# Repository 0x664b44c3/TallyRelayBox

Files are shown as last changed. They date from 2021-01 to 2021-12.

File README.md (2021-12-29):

# TallyRelayBox
RS-422 Tally relay box using the TSL protocol

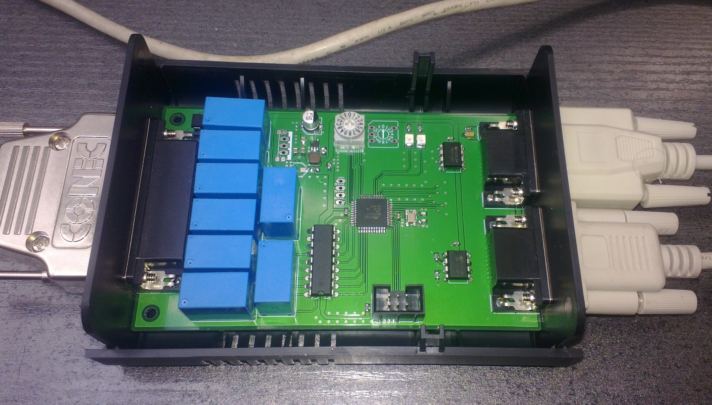
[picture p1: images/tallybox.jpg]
assembled board


## Tally?

In broadcast the "red on air lamps" on cameras, monitors etc are called "Tally". They are one of the most basic and important means of communications in a studio.
Telling both the talent(s) and the technical crew (camera operators, director, etc) which image is on air (or about to be on air next).
This hardware design is a small project that fits into this niche by extracting eight channels of tally information from an RS-422/485 link carrying TSL UMD data. 
TSL's UMD protocol is one of the de-acto standards in "the industry" when it comes to distributing UMD - under monitor display - information (see tslproducts.com) 
with several other manufacturer's rack mount monitors or multy viewers understanding it.

This UMD data can easily be generated by a PC from your video mixer software (say OBS) or by writing an adapter application to translate your hardware mixer's protocol 
to TSL if the data link is not already using this protocol anyways.

The protocol obviously could be changed to whatever you feel is appropiate. Pull requests are welcome.

## Hardware

This design is based on a ATMega324PB.

Power supply can be in the range of 8 to 24V (change relays to your operating voltage!)

## Component sourcing

Most components in this design are widely available standard parts (Mouser etc are your friends for the switchmode regulator and inductor).
If used at 12V a 7805 linear regulator can be fitted as an alternative.
The provided CAD data allows easy adaption to your
local or preferred supplier. The board can be edited in the eagle freeware version if it is shortened by a few millimeters.
Current board size is designed to fit into a cheap plastic enclosure available from Reichelt Electronik in Germany 
(https://www.reichelt.de/kleingehaeuse-135-x-95-x-45-mm-eurobox-sw-p50429.html?&nbc=1). Similar enclosures should be readily available
from several suppliers. The relays used can either be TE  OJE-SS-112LMH or other types with a compatible footprint (like SonChuan 307 series).

## Compiling and flashing

I use avr-gcc 10.2.0 with GNU make on Linux for compiling this project. Your build environment may vary.
You may have to source the device definitions for the Mega324PB from Microchip to be able to compile this project.

See setup_fuses.sh for the fuse setting of the controller.

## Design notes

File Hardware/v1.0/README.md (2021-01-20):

Layout and schematics in EAGLE 6.0 file format.
This version still has an error in the RS-422 pinout (3/8 swapped)
A corrected version will be added later on.

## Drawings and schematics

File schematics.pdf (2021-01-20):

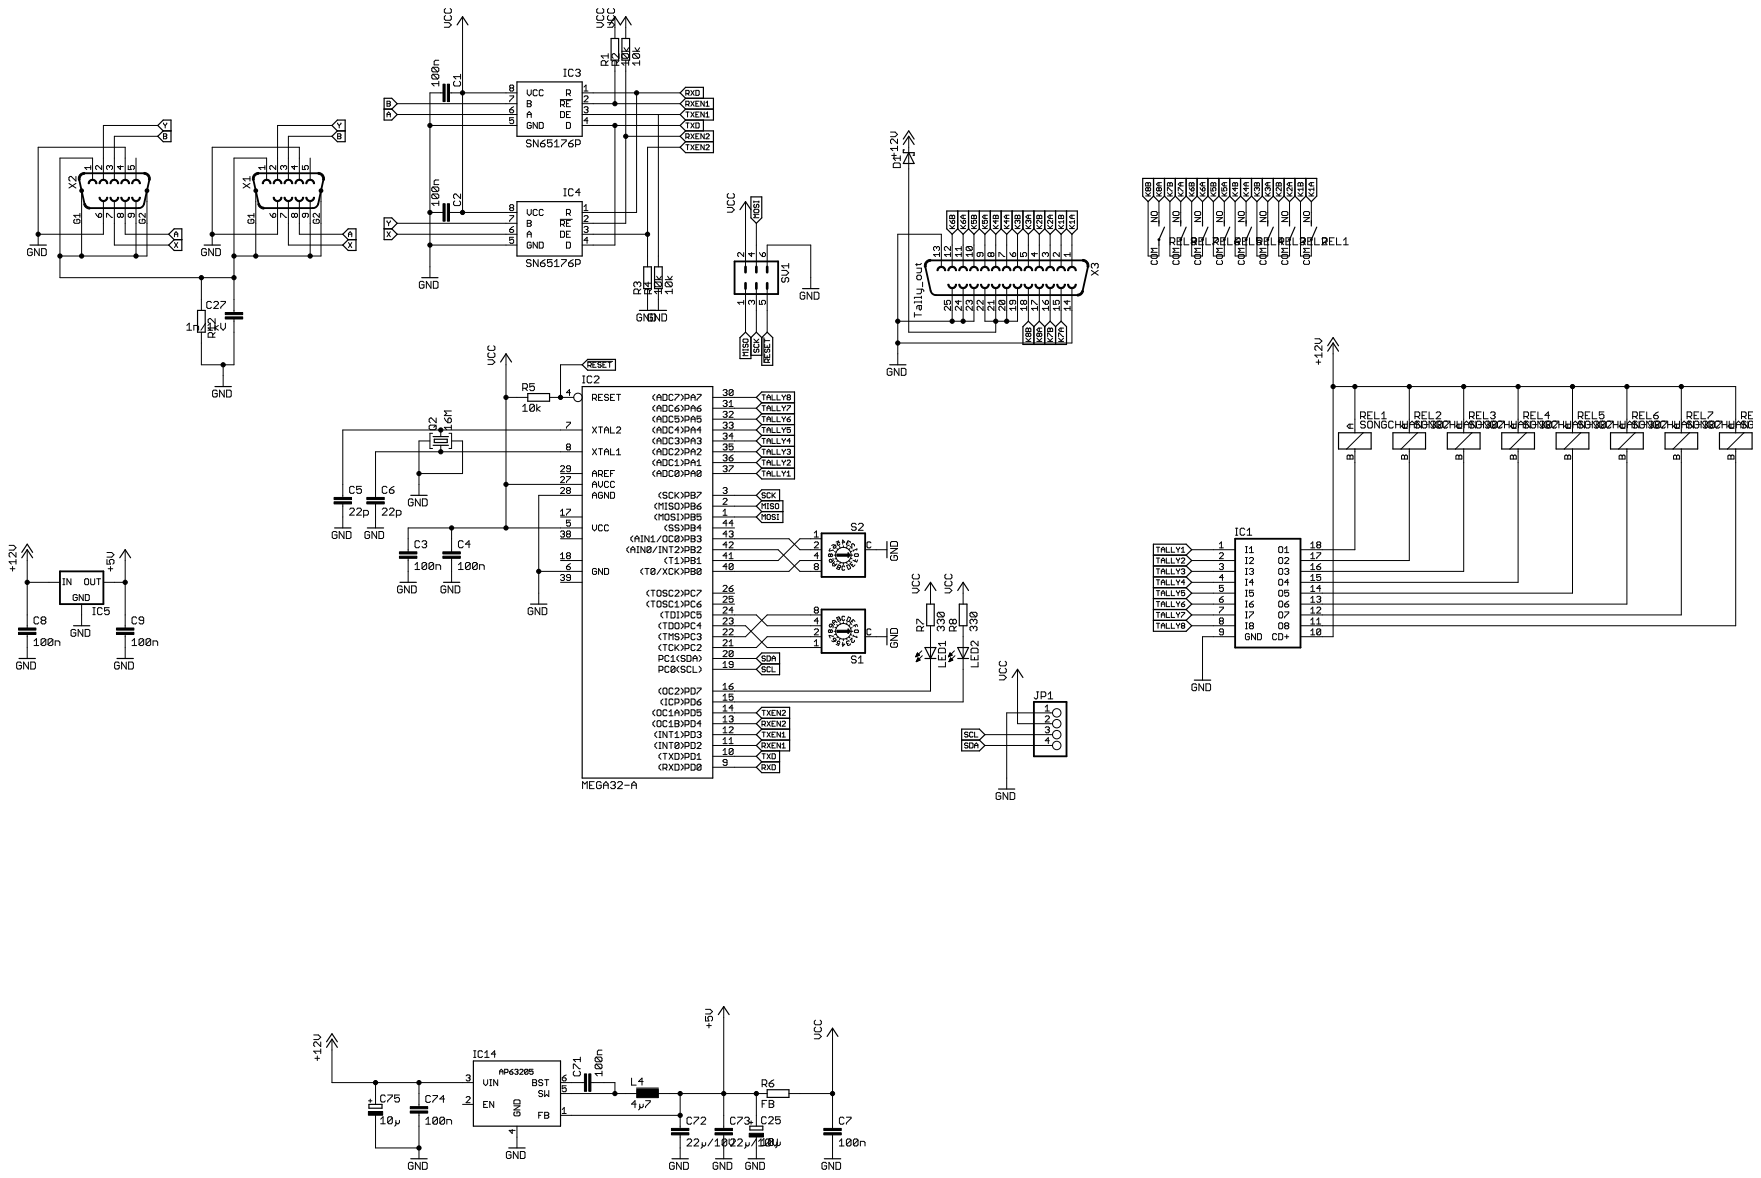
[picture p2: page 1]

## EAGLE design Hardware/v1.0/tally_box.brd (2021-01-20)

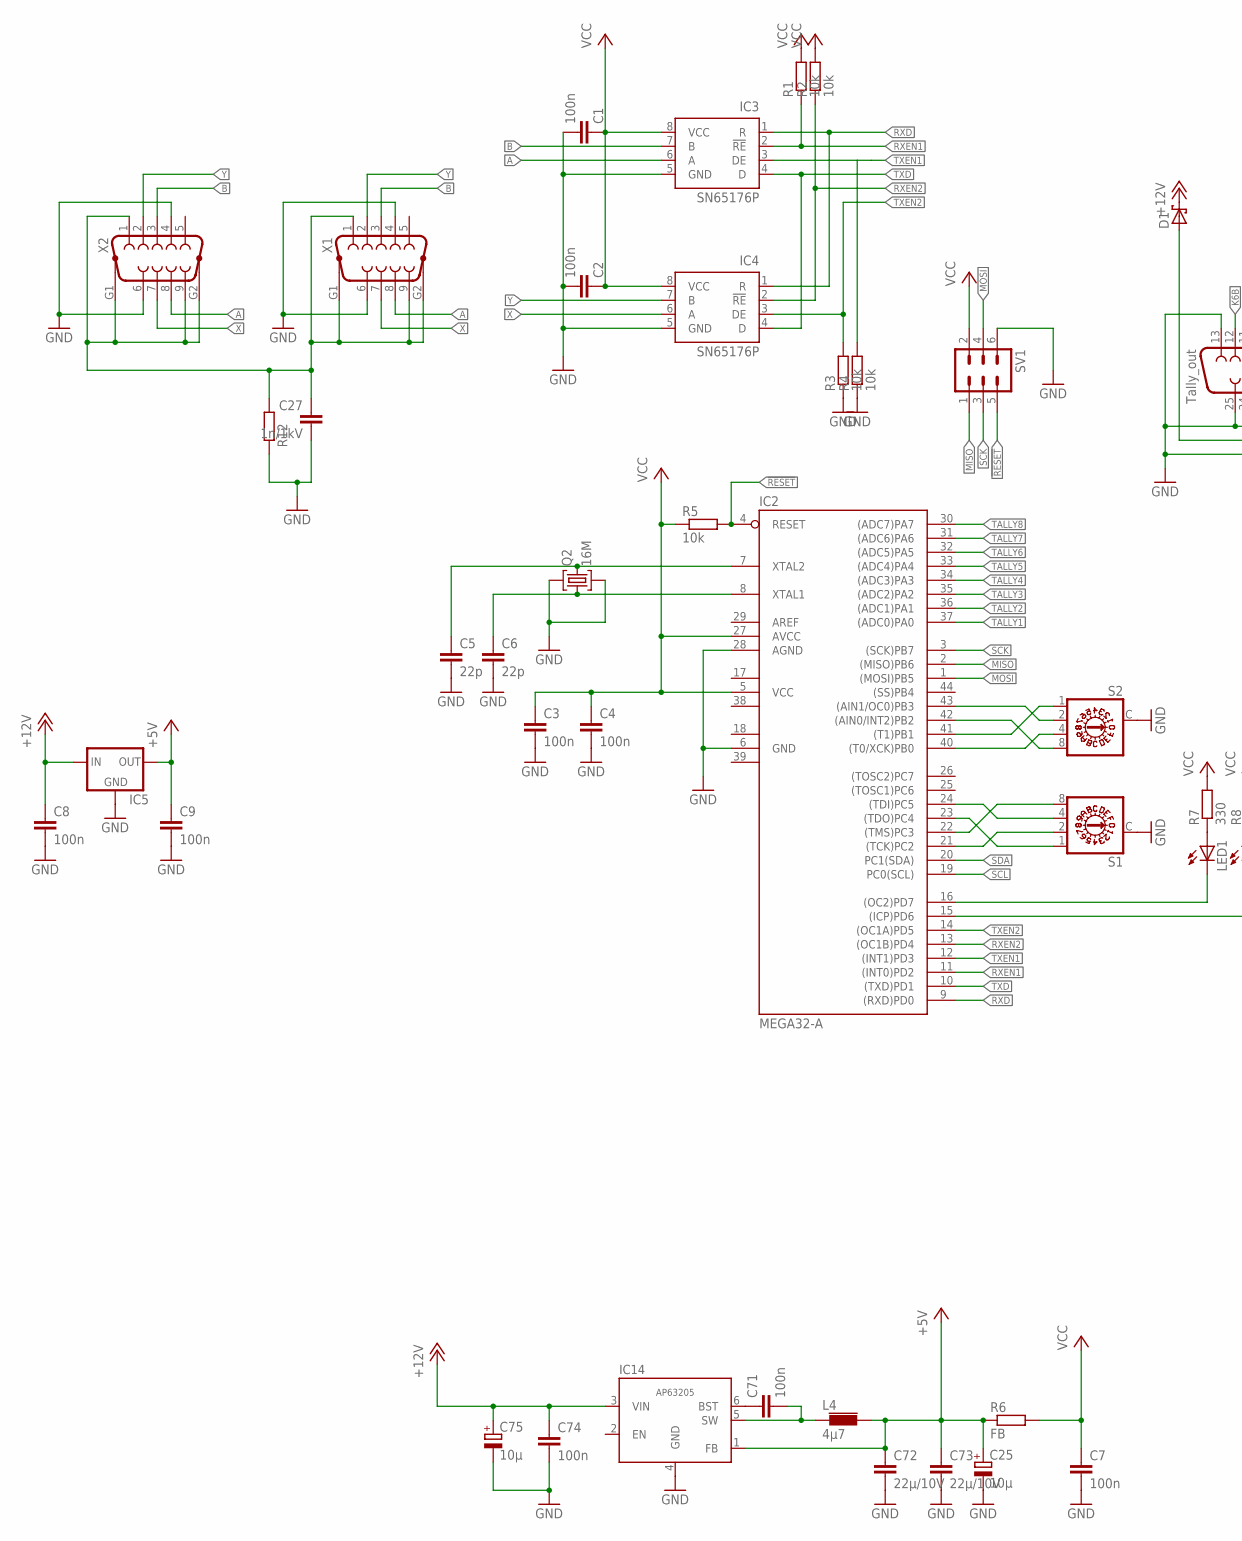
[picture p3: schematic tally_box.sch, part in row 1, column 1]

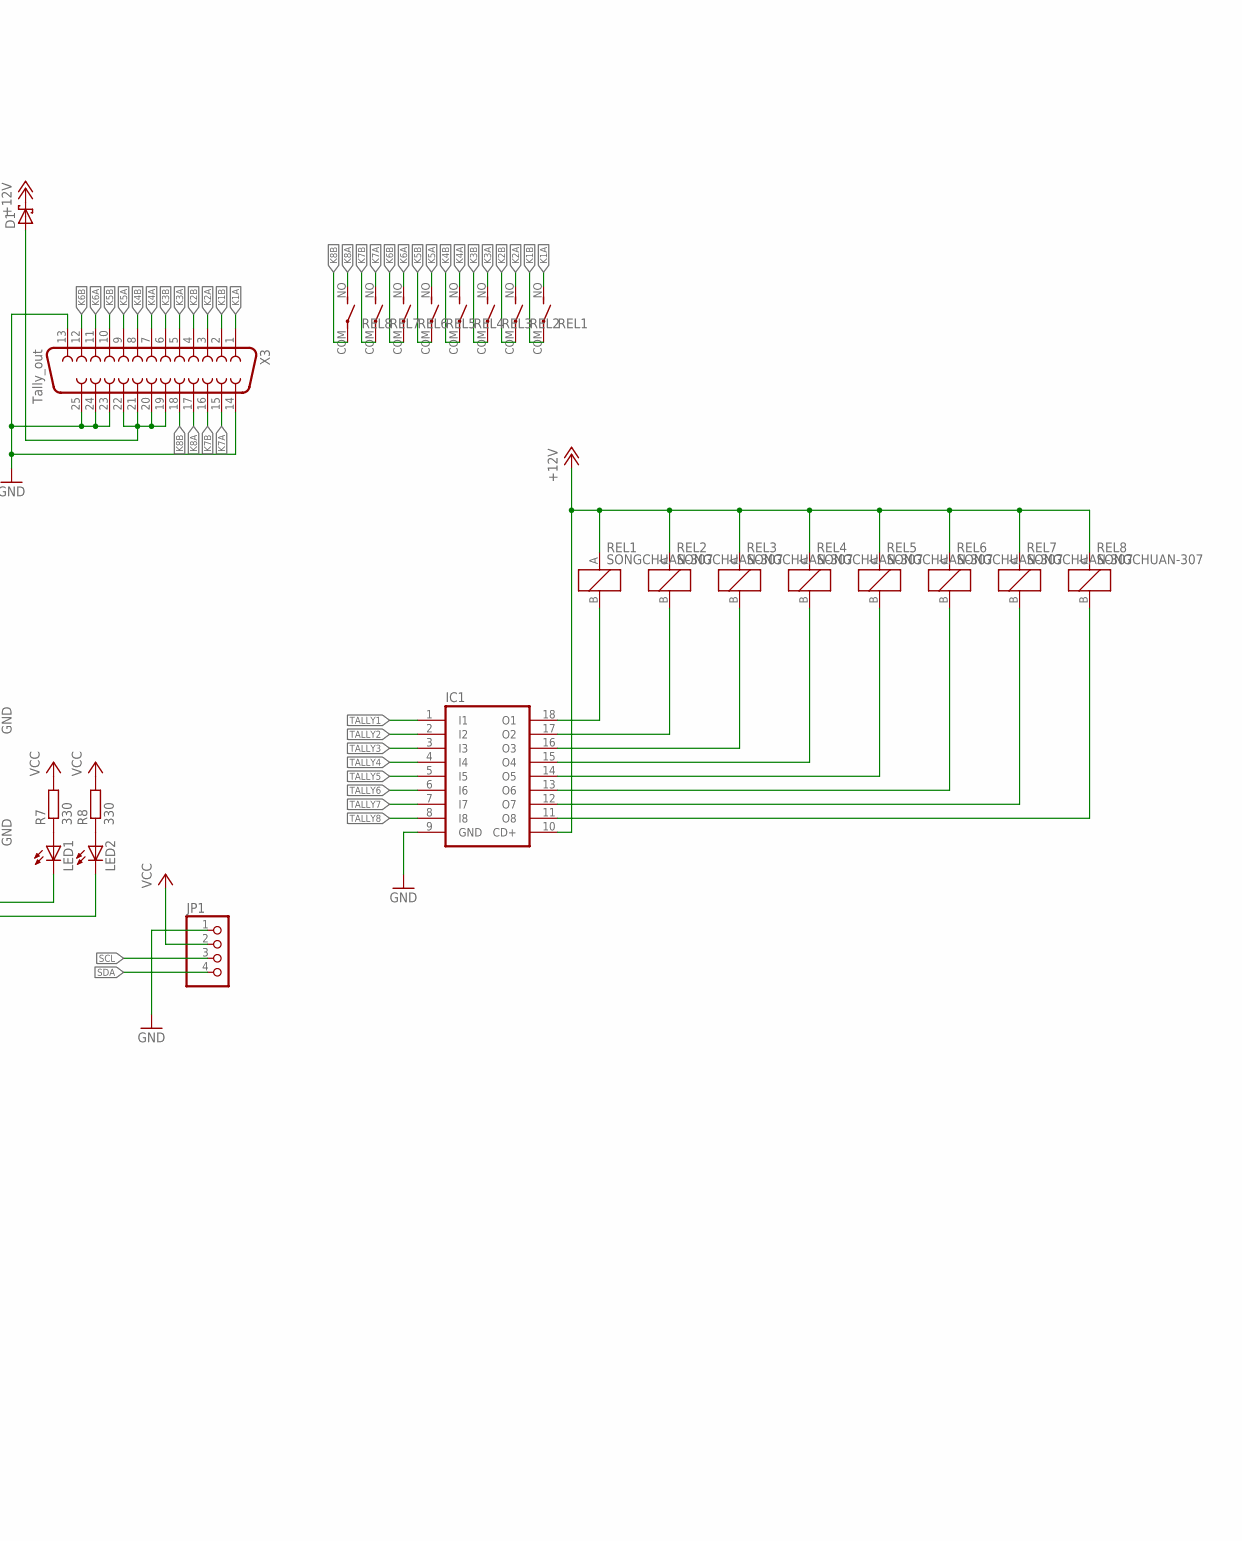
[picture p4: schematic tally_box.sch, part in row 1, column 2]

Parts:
C1, C2, C3, C4, C7: 100n; C0603
C5, C6: 22p; C0603
C8, C9, C71, C74: 100n; C0805
C25: 10µ; PANASONIC_C
C27: 1n/1kV; C1206
C72, C73: 22µ/10V; C0805
C75: 10µ; PANASONIC_D
D1: SCHOTTKY-DIODESMD; SMB
IC1: ULN2803A; DIL18
IC2: MEGA32-A; TQFP44
IC3, IC4: SN65176P; DIL08
IC5: 78XXS
IC14: AP63205; SOT23-6L
JP1: PINHD-1X4; 1X04
L4: 4µ7; TYA4020
LED1, LED2: LED-TOPLED; P-LCC-2
Q2: 16M; MJ
R1, R2, R3, R4, R5: 10k; R0603
R6: FB; R0805
R7, R8: 330; R0603
R12: R-EU_R0603; R0603
REL1, REL2, REL3, REL4, REL5, REL6, REL7, REL8: SONGCHUAN-307; SONCHUAN-307
S1, S2: A1353HEX
SV1: ML6
X1, X2: F09HP
X3: Tally_out; F25HP

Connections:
!RESET!: IC2.4 (RESET), R5.2, SV1.5
+5V: C9.1, C25.+, C72.1, C73.1, IC5.OUT, IC14.1 (FB), L4.2, R6.1
+12V: C8.1, C74.1, C75.+, D1.C, IC1.10 (CD+), IC5.IN, IC14.3 (VIN), REL1.A (+), REL2.A (+), REL3.A (+), REL4.A (+), REL5.A (+), REL6.A (+), REL7.A (+), REL8.A (+)
A: IC3.6 (A), X1.8, X2.8
AREF: IC2.29 (AREF)
B: IC3.7 (B), X1.3, X2.3
GND: C1.2, C2.2, C3.2, C4.2, C5.2, C6.2, C7.2, C8.2, C9.2, C25.-, C27.2, C72.2, C73.2, C74.2, C75.-, IC1.9 (GND), IC2.6 (GND), IC2.28 (AGND), IC3.5 (GND), IC4.5 (GND), IC5.GND, IC14.4 (GND), JP1.1, Q2.2 (G1), Q2.4 (G2), R3.1, R4.1, R12.1, S1.C, S2.C, SV1.6, X1.4, X1.6, X2.4, X2.6, X3.13, X3.14, X3.23, X3.24, X3.25
GND1: IC2.18 (GND1)
GND2: IC2.39 (GND2)
K1A: REL1.NO (S), X3.1
K1B: REL1.COM, X3.2
K2A: REL2.NO (S), X3.3
K2B: REL2.COM, X3.4
K3A: REL3.NO (S), X3.5
K3B: REL3.COM, X3.6
K4A: REL4.NO (S), X3.7
K4B: REL4.COM, X3.8
K5A: REL5.NO (S), X3.9
K5B: REL5.COM, X3.10
K6A: REL6.NO (S), X3.11
K6B: REL6.COM, X3.12
K7A: REL7.NO (S), X3.15
K7B: REL7.COM, X3.16
K8A: REL8.NO (S), X3.17
K8B: REL8.COM, X3.18
MISO: IC2.2 ((MISO)PB6), SV1.1
MOSI: IC2.1 ((MOSI)PB5), SV1.4
unnamed: IC1.18 (O1), REL1.B (-)
unnamed: IC1.17 (O2), REL2.B (-)
unnamed: IC1.16 (O3), REL3.B (-)
unnamed: IC1.15 (O4), REL4.B (-)
unnamed: IC2.23 ((TDO)PC4), S1.1
unnamed: IC2.21 ((TCK)PC2), S1.2
unnamed: IC2.22 ((TMS)PC3), S1.8
unnamed: IC2.24 ((TDI)PC5), S1.4
unnamed: IC1.14 (O5), REL5.B (-)
unnamed: IC1.13 (O6), REL6.B (-)
unnamed: IC1.12 (O7), REL7.B (-)
unnamed: IC1.11 (O8), REL8.B (-)
unnamed: IC2.43 ((AIN1/OC0)PB3), S2.2
unnamed: D1.A, X3.19, X3.20, X3.21, X3.22
unnamed: IC2.42 ((AIN0/INT2)PB2), S2.8
unnamed: IC2.41 ((T1)PB1), S2.1
unnamed: IC2.40 ((T0/XCK)PB0), S2.4
unnamed: C5.1, IC2.7 (XTAL2), Q2.3 (2)
unnamed: C6.1, IC2.8 (XTAL1), Q2.1
unnamed: IC2.16 ((OC2)PD7), LED1.C
unnamed: IC2.15 ((ICP)PD6), LED2.C
unnamed: LED1.A, R7.1
unnamed: LED2.A, R8.1
unnamed: C71.1, IC14.6 (BST)
RXD: IC2.9 ((RXD)PD0), IC3.1 (R), IC4.1 (R)
RXEN1: IC2.11 ((INT0)PD2), IC3.2 (!RE), R1.1
RXEN2: IC2.13 ((OC1B)PD4), IC4.2 (!RE), R2.1
SCK: IC2.3 ((SCK)PB7), SV1.3
SCL: IC2.19 (PC0(SCL)), JP1.3
SDA: IC2.20 (PC1(SDA)), JP1.4
TALLY1: IC1.1 (I1), IC2.37 ((ADC0)PA0)
TALLY2: IC1.2 (I2), IC2.36 ((ADC1)PA1)
TALLY3: IC1.3 (I3), IC2.35 ((ADC2)PA2)
TALLY4: IC1.4 (I4), IC2.34 ((ADC3)PA3)
TALLY5: IC1.5 (I5), IC2.33 ((ADC4)PA4)
TALLY6: IC1.6 (I6), IC2.32 ((ADC5)PA5)
TALLY7: IC1.7 (I7), IC2.31 ((ADC6)PA6)
TALLY8: IC1.8 (I8), IC2.30 ((ADC7)PA7)
TXD: IC2.10 ((TXD)PD1), IC3.4 (D), IC4.4 (D)
TXEN1: IC2.12 ((INT1)PD3), IC3.3 (DE), R4.2
TXEN2: IC2.14 ((OC1A)PD5), IC4.3 (DE), R3.2
VCC: C1.1, C2.1, C3.1, C4.1, C7.1, IC2.5 (VCC), IC2.27 (AVCC), IC3.8 (VCC), IC4.8 (VCC), JP1.2, R1.2, R2.2, R5.1, R6.2, R7.2, R8.2, SV1.2
VCC1: IC2.17 (VCC1)
VCC2: IC2.38 (VCC2)
VSW_5V: C71.2, IC14.5 (SW), L4.1
X: IC4.6 (A), X1.7, X2.7
XGND: C27.1, R12.2, X1.1, X1.9, X1.G1, X1.G2, X2.1, X2.9, X2.G1, X2.G2
Y: IC4.7 (B), X1.2, X2.2

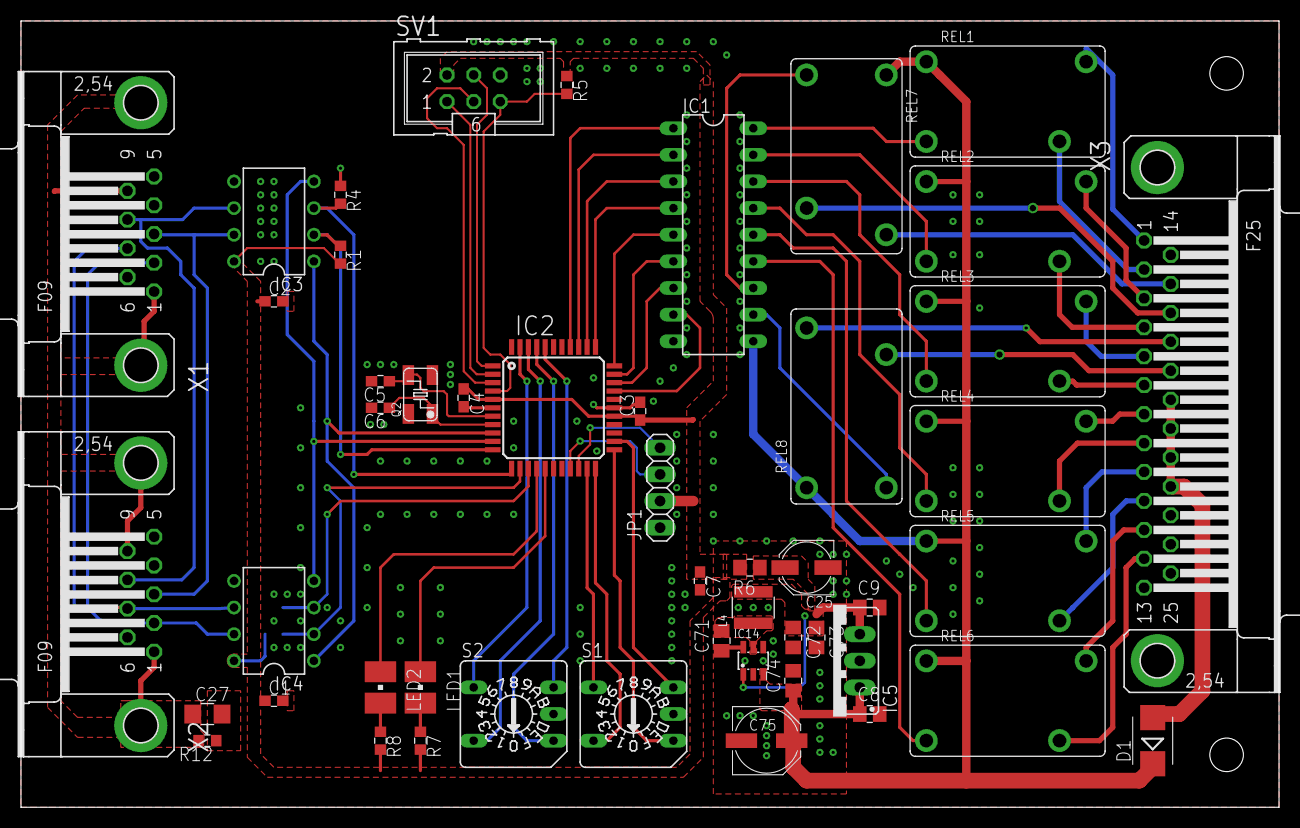
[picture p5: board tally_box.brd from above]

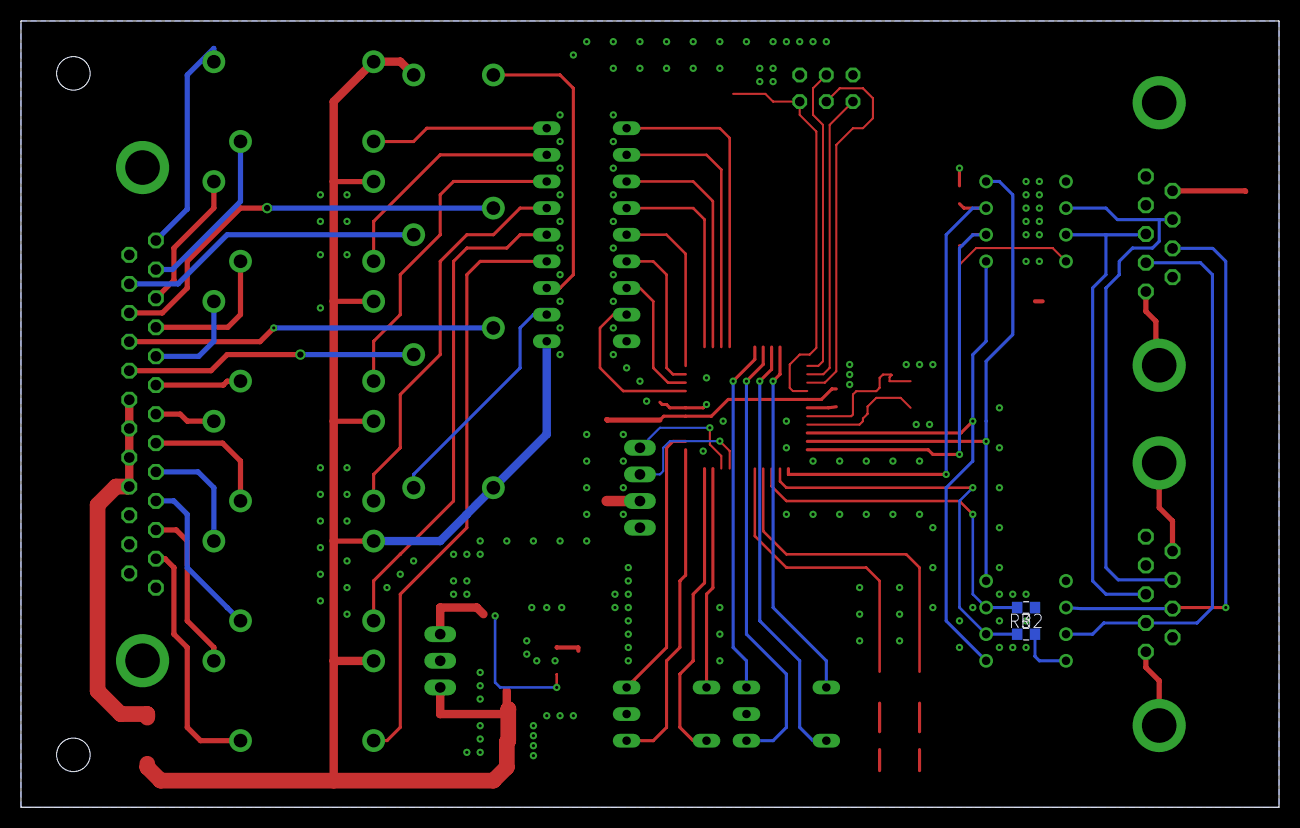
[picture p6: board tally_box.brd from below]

Board: 2 copper layers, 120.0 x 75.0 mm, 51 parts (2 on the bottom side), 70 nets.

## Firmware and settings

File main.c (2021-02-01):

#include <string.h>
#include <inttypes.h>
#include <avr/interrupt.h>
#include <avr/eeprom.h>
#include <avr/io.h>
#include <util/delay.h>
#include <avr/pgmspace.h>
#include "gptimer.h"
#include "tsl.h"
#include "uart.h"

uint32_t baud = 38400;

//comment out if you use hexadecimal address switches
#define ADDR_BCD


//enable debug output un RS-422
//#define ENABLE_DEBUG


//if commented out, uses Pair 3+8 for Rx, 2+7 for Tx
//if set: uses Pair 2+7 for Rx, 3+8 for Tx

//#define RS422_SWAP ///< use Pair 2+7 for Rx, 3+8 for Rx

//enable EVEN parity
#define ENABLE_PARITY

typedef union {
	uint16_t u16;
	struct {
		uint8_t u8l;
		uint8_t u8h;
	};
} accu_t;

uint8_t swap_bits_dip1(uint8_t in)
{
	uint8_t ret = (in&1)?2:0;
	ret        |= (in&2)?8:0;
	ret        |= (in&4)?1:0;
	ret        |= (in&8)?4:0;
	return ret;
}
uint8_t swap_bits_dip2(uint8_t in)
{
	uint8_t ret = (in&8)?2:0;
	ret        |= (in&4)?8:0;
	ret        |= (in&2)?1:0;
	ret        |= (in&1)?4:0;
	return ret;
}

void init_hw(void)
{
	DDRA=0xff;
	DDRB=0xb0;
	DDRC=0x00;
	PORTD=0x14;
	DDRD=0xfe;
	PORTB=0x0f;
	PORTC=0x3c;
}


unsigned char hex[]="0123456789abcdef";
uint16_t lastDBG=0;
void show_u16(uint16_t val)
{
	uart_putc(hex[val>>12]);
	uart_putc(hex[(val>>8)&15]);
	uart_putc(hex[(val>>4)&15]);
	uart_putc(hex[val&15]);
}
void show_timestamp(const char* pstr)
{
	uint16_t tmp=systick;
	uint16_t diff = tmp-lastDBG;
	lastDBG = tmp;
	if (pstr)
	{
		uart_puts_p(pstr);
		uart_putc(' ');
	}
	uart_puts_p(PSTR("TS 0x"));
	show_u16(tmp);
	uart_puts_p(PSTR(" +"));
	show_u16(diff);
	uart_puts_p(PSTR("\r\n"));
}

uint8_t tmr_msg=0;
uint8_t tslAddr=0;
void tslCallback(uint8_t addr, uint8_t bright, uint8_t tally, unsigned char * text)
{
	timer_set(tmr_msg, 10);
	if ((addr>=tslAddr) && (addr<tslAddr+8))
	{
		uint8_t channel = addr - tslAddr;
		PORTA&=~_BV(channel);
		if (tally&1)
			PORTA|=_BV(channel);
	}
}

const unsigned char error_mask = _BV(FE0)  |
                                 _BV(DOR0) |
                                 _BV(UPE0);
ISR(USART0_RX_vect)
{
	unsigned char status = UCSR0A;
	unsigned char data   = UDR0;
#ifndef IGNORE_UART_ERRORS
	if (status & error_mask)
	{
		tsl_reset();
	}
	else
	{
		tsl_onChar(data);
	}
#else
	tsl_onChar(data);
#endif
}

void initUart(void)
{
	    UCSR0B = 0;
		uint16_t ubrr = (((F_CPU) + 8UL * (baud)) / (16UL * (baud)) -1UL);

		UBRR0L = ubrr & 0xff;
		UBRR0H = ubrr >> 8;
#ifdef ENABLE_PARITY
		UCSR0C = _BV(UCSZ00)|_BV(UCSZ01) |
		         _BV(UPM01);
#else
		UCSR0C = _BV(UCSZ00)|_BV(UCSZ01);
#endif
		UCSR0A = 0;                                              // clear error flags, disable U2X and MPCM
		UCSR0B = (1<<RXEN0)|(1<<TXEN0);
}

int main(void) {
	timer_init();
	tsl_setCallback(&tslCallback);
	init_hw();
	initUart();
	for(uint8_t d=0;d<250;++d)
		_delay_ms(1);
	PORTD|=0xc0;

#ifdef RS422_SWAP
	//enable receive on 2+7
	PORTD&=~_BV(4);
#else
	//enable receive on 3+8
	PORTD&=~_BV(2);
#endif

#ifdef ENABLE_DEBUG
#ifdef RS422_SWAP
	//enable transmit on 3+8 (debug)
	PORTD|=_BV(3);
#else
	//enable transmit on 2+7 (debug)
	PORTD|=_BV(5);
#endif
#endif

	uint8_t tmr_blink = timer_reg();
	tmr_msg = timer_reg();

	uart_puts_p(PSTR("TSL Adapter. Enter main loop.\r\n"));

	//enable rx interrupt
	UCSR0B |= _BV(RXCIE0);
	//enable interrupts
	sei();
	while(1)
	{

		uint8_t addr_low  = swap_bits_dip1(((~PINC)&0x3c)>>2);
		uint8_t addr_high = swap_bits_dip2((~PINB)&0x0f);
		uint8_t addr_new=0;
#ifdef ADDR_BCD
		addr_new = addr_low + addr_high*10;
#else
		addr_new = (addr_high<<4) | addr_low;
#endif
		if (addr_new != tslAddr)
		{
			PORTA=0;
			tslAddr = addr_new;
#ifdef ENABLE_DEBUG
			uart_puts_p(PSTR("TSL Addr: 0x"));
			uart_putc(hex[addr_new>>4]);
			uart_putc(hex[addr_new&15]);
			uart_puts_p(PSTR(" ("));
			uart_putc('0' + tslAddr / 100);
			uart_putc('0' + (tslAddr % 100)/ 10);
			uart_putc('0' + tslAddr % 10);
			uart_puts_p(PSTR(").\r\n"));
#endif
		}

		//activity LED
		if (timer_expired(tmr_msg))
			PORTD|=_BV(7);
		else
			PORTD&=~_BV(7);

		//system LED
		if (timer_expired(tmr_blink))
		{
			timer_set(tmr_blink, 500);
			PORTD^=0x40;
		}
	}
}

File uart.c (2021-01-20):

#include <avr/io.h>
#include <avr/pgmspace.h>
void uart_putc(unsigned char data)
{
	/* Wait for empty transmit buffer */
	while ( !( UCSR0A & (1<<UDRE0)) );
	/* Put data into buffer, sends the data */
	UDR0 = data;

}/* uart_putc */


/*************************************************************************
Function: uart_puts()
Purpose:  transmit string to UART
Input:    string to be transmitted
Returns:  none
**************************************************************************/
void uart_puts(const char *s )
{
	while (*s)
		uart_putc(*s++);

}/* uart_puts */


/*************************************************************************
Function: uart_puts_p()
Purpose:  transmit string from program memory to UART
Input:    program memory string to be transmitted
Returns:  none
**************************************************************************/
void uart_puts_p(const char *progmem_s )
{
	register char c;

	while ( (c = pgm_read_byte(progmem_s++)) )
		uart_putc(c);

}/* uart_puts_p */

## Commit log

2021-01-20 Added Hardware
    [tally_box.brd, tally_box.sch]
2021-01-20 Added descriptions on building and AVR fuse settings
2021-01-20 Added schematics PDF
2021-02-19 added image of a (mostly) finished board
